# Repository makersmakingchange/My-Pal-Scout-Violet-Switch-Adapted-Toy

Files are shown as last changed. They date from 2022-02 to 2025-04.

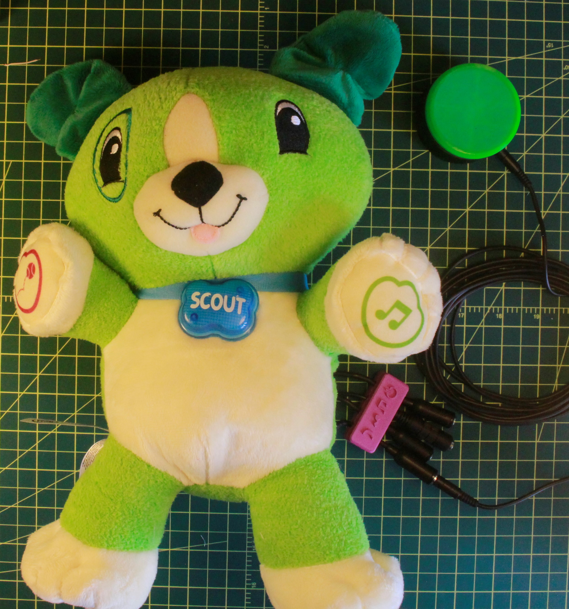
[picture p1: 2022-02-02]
Photos/_MG_9257 (2).JPG

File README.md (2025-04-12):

# My-Pal-Scout-Violet-Switch-Adapted-Toy
Solderless toy hack for My Pal toys that allows for switch adaptation

## Overview

The switch adapted My Pal Scout/Violet sings songs and can be controlled with accessible switches that have a 3.5mm jack. The My Pal is a LeapFrog toy that sings lullabies and learning songs, and has activities with numbers, animals, food, and more.

## Usage

You can use the My Pal Scout/Violet by plugging in one to four AT switches. The cable clamp labels which function each audio lead controls. Then, press the AT switches, or the in-toy buttons, to activate the various songs and activities.

## Build Instructions

You can build the My Pal Scout/Violet by following the Assembly Guide attached. Follow the “How to prep your 3.5mm headphone jack” tutorial first to prepare for this toy adaption.

## Bill of Materials
Links given in BOM under documentation

 - 1 x LeapFrog My Pal Scout or Violet Toy (https://www.amazon.ca/LeapFrog-Pal-Violet-English-Version/dp/B00D2KZ1ZY?th=1)
 - 4 x 3.5mm Female Headphone jacks (something like two of  these cut in half: (Amazon Canada)
 - 8 x Crimp Connectors (Amazon Canada)
 - 1 x 3D Printed Clamp
 - 2 x #4 Metal Screw, 3/8″ Length (Amazon Canada)
 - 1 x 4" Zip Tie (Amazon Canada)
 - 1 x 18" Zip Tie (Amazon Canada
 - Electrical Tape

Note: Other wire connections aside from the crimp connectors can be used, such as UR2 connectors, Marrettes, or even soldering the connections.

## Tools
 - Needle Nose Pliers (or Wire Crimpers, or Vise Grips)
 - Crimping tool is recommended if available
 - Wire Cutters
 - Wire Strippers

## Attribution

 - Original Device: ATMakers
 - Updated Design: Makers Making Change

<!-- ABOUT MMC START -->
## About Makers Making Change
[Makers Making Change Logo](https://www.makersmakingchange.com/)

Makers Making Change is a program of [Neil Squire](https://www.neilsquire.ca/), a Canadian non-profit that uses technology, knowledge, and passion to empower people with disabilities.

Makers Making Change leverages the capacity of community based Makers, Disability Professionals and Volunteers to develop and deliver affordable Open Source Assistive Technologies.

 - Website: [www.MakersMakingChange.com](https://www.makersmakingchange.com/)
 - GitHub: [makersmakingchange](https://github.com/makersmakingchange)
 - Bluesky: [@makersmakingchange.bsky.social](https://bsky.app/profile/makersmakingchange.bsky.social)
 - Instagram: [@makersmakingchange](https://www.instagram.com/makersmakingchange)
 - Facebook: [makersmakechange](https://www.facebook.com/makersmakechange)
 - LinkedIn: [Neil Squire Society](https://www.linkedin.com/company/neil-squire-society/)
 - Thingiverse: [makersmakingchange](https://www.thingiverse.com/makersmakingchange/about)
 - Printables: [MakersMakingChange](https://www.printables.com/@MakersMakingChange)

### Contact Us
For technical questions, to get involved, or to share your experience we encourage you to [visit our website](https://www.makersmakingchange.com/) or [contact us](https://www.makersmakingchange.com/s/contact).
<!-- ABOUT MMC END -->

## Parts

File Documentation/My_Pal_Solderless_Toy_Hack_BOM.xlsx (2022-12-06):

Device: My Pal Solderless Toy Hack |  |  |  |  |  | Total Cost | Total Print time (hr) | Total filament (g)
Version: V1.0 | Date Created: 1/31/2022 |  |  |  |  | $48.66 | 0.77 | 9.49
Commercial Parts:
Part type (Electrical. Mechanical, Sanitization, ect) | Part | Quantity Needed | Pkg Quantity | Price per package | Price per Unit | Price for qty needed |  | Link
Toy | My Pal Scout/Violet | 1 | 1 | $25.97 | $25.97 | $25.97 |  | https://www.amazon.ca/LeapFrog-Pal-Violet-English-Version/dp/B00D2KZ1ZY?th=1
Electrical | 3.5mm Female-Female Audio Leads | 2 | 1 | $9.99 | $9.99 | $19.98 |  | ANDTOBO Aux Connector ,3.5mm TRRS Female to Female Stereo Coupler Plug Adapter- 3.3 Ft : Amazon.ca: Electronics (https://www.amazon.ca/ANDTOBO-Connector-Female-Coupler-Adapter/dp/B08CXNHXZQ)
Electrical | Crimp Connectors | 8 | 100 | $16.29 | $0.16 | $1.30 |  | https://www.amazon.ca/dp/B09D6WSGBL?s=hi
Hardware | 4" Zip Tie | 1 | 300 | 10.59 | $0.04 | $0.04 |  | https://www.amazon.ca/Inch-300pcs-Nylon-Cable-White/dp/B07JHQFV29?s=hi
Hardware | 18" Zip Tie | 1 | 100 | 30.99 | $0.31 | $0.31 |  | https://www.amazon.ca/Industrial-Durable-Binding-Branches-Bundling/dp/B08B3S5Y65?s=hi
Hardware | #4 Metal Screw. 3/8" Length | 2 | 25 | 10.34 | $0.41 | $0.83 |  | https://www.amazon.ca/Prime-Line-9018921-Self-Tapping-Phillips-Stainless/dp/B074ZMZZC5?s=hi
3D Printed Parts ESTIMATED PRICING USING 1KG ROLL COST: | $25.00
Part | Description | Quantity Needed | TOTAL Mass (g) | Estimated Price | Print Time (Min) | Link
Cable Clamp Top and Bottom | Secures and labels the cables protruding from the toy. | 1 | 9.49 | $0.24 | 46
 |  |  |  | $0.00
 |  |  |  | $0.00
 |  |  |  | $0.00
 |  |  |  | $0.00
 |  |  | Total Print Cost: | $0.24
Tools for Assembly
#3 Philips Screwdriver
Flush Cutters
Pliers (Crimping tool reccomended)
Alternatives (if there are other sources for some parts link them below)
Part and description | Link
Marrettes in place of crimp connectors | https://www.amazon.ca/dp/B0009K6GB8/ref=twister_B06XWT633Y?th=1
UR2 connectors in place of crimp connectors | https://www.amazon.ca/YOLISTIC-Pack-Splice-Connector-Wire/dp/B098T7QF9L?s=hi
3.5mm Female-Female Audio Leads | 10-02148 Tensility International Corp | Cable Assemblies | DigiKey (https://www.digikey.ca/en/products/detail/tensility-international-corp/10-02148/7606595)

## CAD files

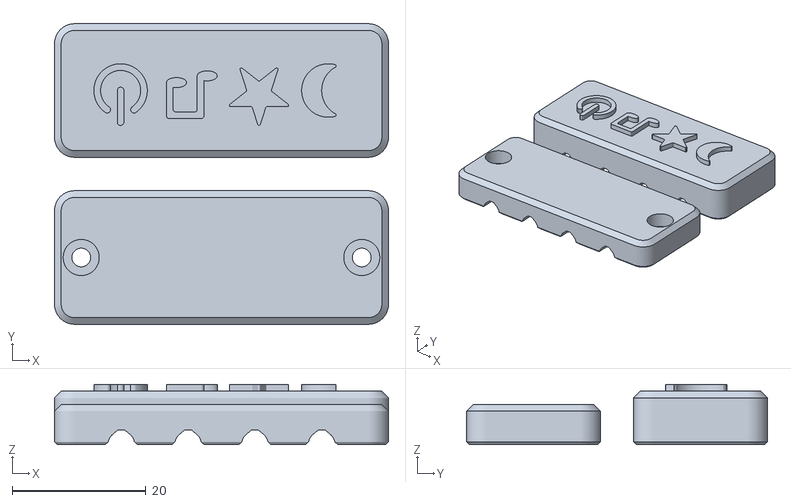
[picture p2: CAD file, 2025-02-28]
3D_Print_Files/Cable-Clamp.stl
50.0 x 45.0 x 9.00

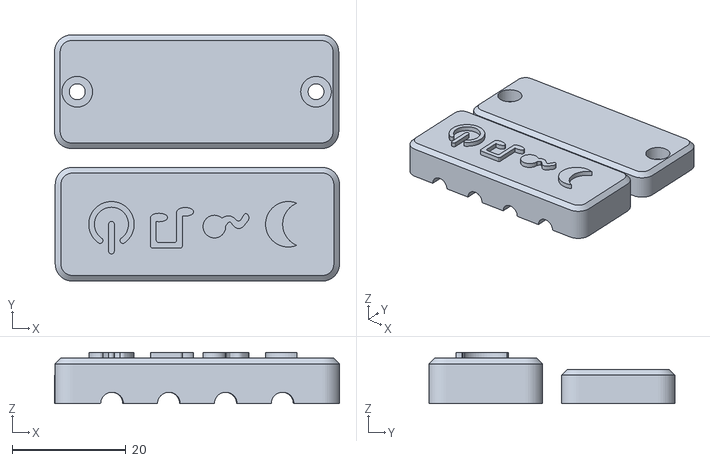
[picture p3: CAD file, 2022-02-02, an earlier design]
3D_Print_Files/Archive - Old version of toy/Cable-Clamp.stl
50.1 x 43.3 x 9.00

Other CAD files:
Design_Files/Cable-Clamp.step
Design_Files/Clamp v2 v11.f3d

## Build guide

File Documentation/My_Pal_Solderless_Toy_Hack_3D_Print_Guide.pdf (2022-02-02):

# 3D Printing Guide Device: My Pal Solderless Toy Hack

### Version: 1.0 Date: 2/1/2022

# Summary

Metrics | *Configuration 1*
Total Print Time (min) | 46
Total Number of Components | 2
Typical Total Mass (g) | 9.49
Typical Number of Print Setups | 1

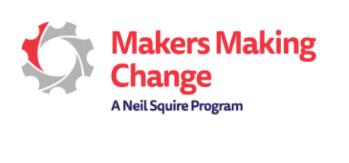
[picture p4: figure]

Print File Name | Qty | Total Print Time (min) | Mass (g) | Infill setting (%) | Material | Notes (support, orientation, special settings)
Cable Clamp.stl | 1 | 46 | 9.49 | 20 | PLA | -Can add a colour change at a layer height of 8.2mm to make the images stand out.

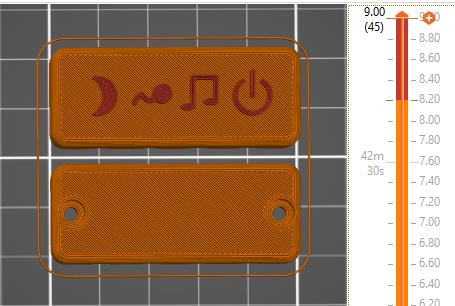
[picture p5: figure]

# Post-Processing

- You may need to clean up some filament from the top surface of the images. This can be done carefully with a knife by scraping off the loose filament.

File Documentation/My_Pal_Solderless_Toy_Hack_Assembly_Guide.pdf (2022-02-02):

# Toy Hack

## COMPONENTS AND TOOLS

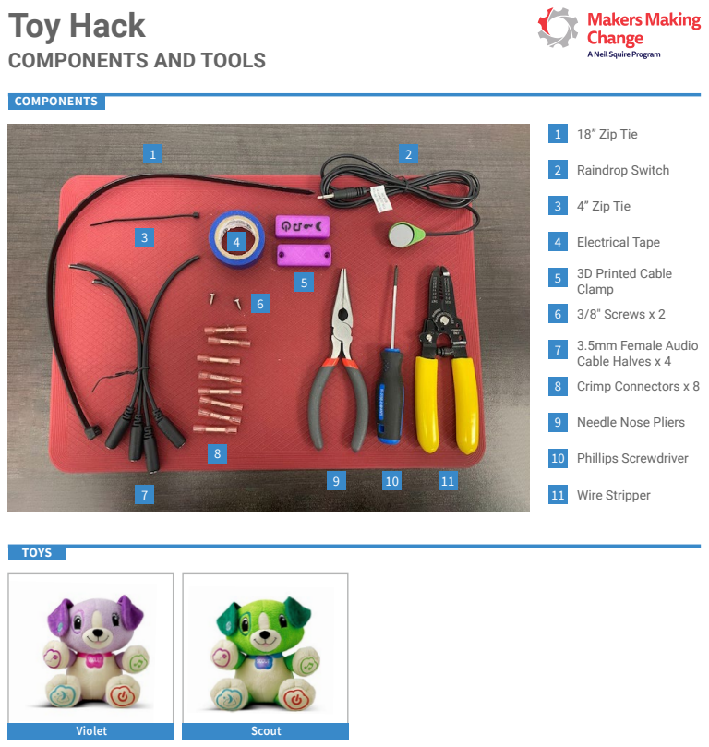
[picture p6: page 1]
COMPONENTS; TOYS; Violet; Scout; 18” Zip Tie; Raindrop Switch; 4” Zip Tie; Electrical Tape; 3D Printed Cable; Clamp; 3/8″ Screws x 2; Crimp Connectors x 8; Needle Nose Pliers; Phillips Screwdriver; Wire Stripper; 3.5mm Female Audio; Cable Halves x 4

V1.0 | November 2021

## My Pal Solderless Toy Hack

## ASSEMBLY GUIDE

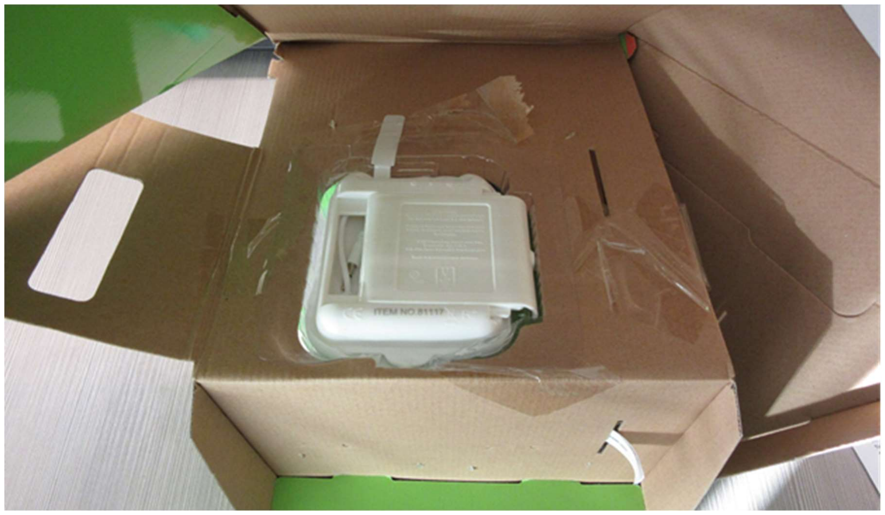
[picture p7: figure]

© 2021 by <Author>. This work is licensed under the CC BY SA 4.0 License: http://creativecommons.org/licenses/by-sa/4.0
Files available at <Replace with MMC Library Link> | Page 2 of 9

Assembly Instructions

### Step 1

Opening the toy:

a) Open the package carefully to unveil the internal battery case.

### Note: It is ideal to leave the toy in the box when doing this hack so it can easily be

repackaged and sent to the end user.

V1.0 | November 2021

## My Pal Solderless Toy Hack

## ASSEMBLY GUIDE

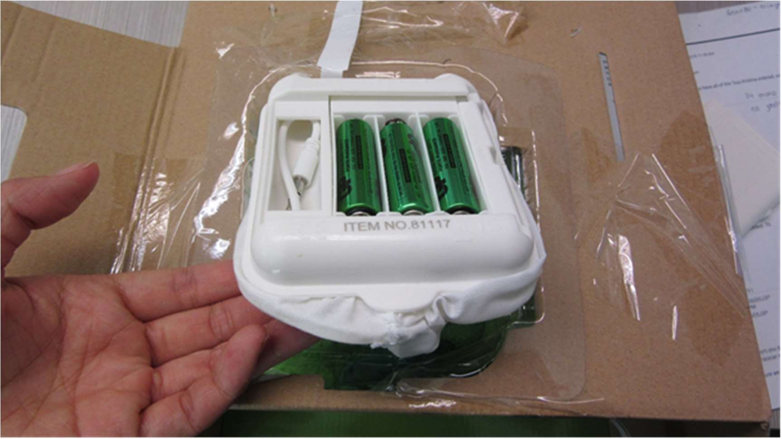
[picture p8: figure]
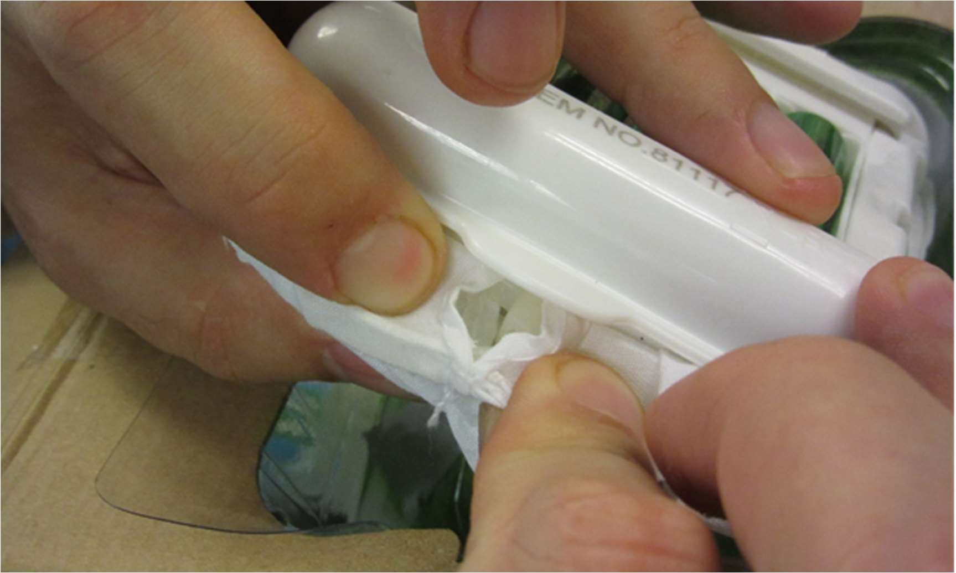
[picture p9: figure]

Files available at <Replace with MMC Library Link> | Page 3 of 9
b) Remove the case from the package but don’t cut the zip tie attaching Violet/Scout to the box. Take out the three AA batteries and set them aside.
c) Near the bottom of the case by the printed “Item No.”, carefully tear the fabric by 1cm to expose the zip tie underneath. Cut off the zip tie knot to release the casing from the fabric.
d) Carefully pull the white casing out of the fabric to expose the wires coming out the back.

V1.0 | November 2021

## My Pal Solderless Toy Hack

## ASSEMBLY GUIDE

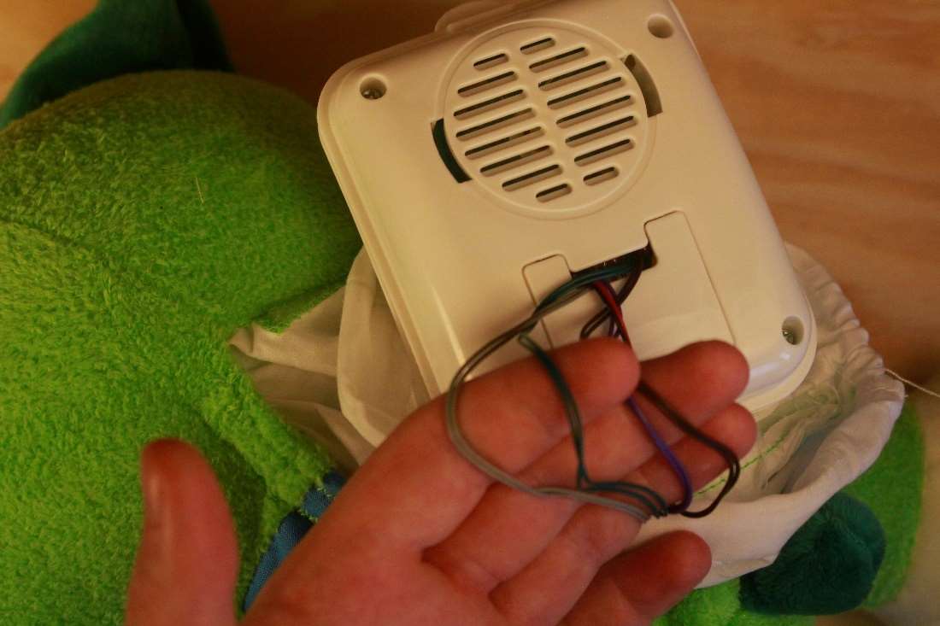
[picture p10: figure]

Files available at <Replace with MMC Library Link> | Page 4 of 9

### Step 2

Wire connections:

a) Locate the pairs of wires going down each limb of the toy and select one pair. The 4 wire pairs in this toy are coloured as grey, green, purple, and brown. (Order as seen in the photo below)
b) Cut one of the wires in the pair and strip 1cm from each new end, then twist these exposed ends back together. Do the same with the other wire in the pair.

## My Pal Solderless Toy Hack

## ASSEMBLY GUIDE

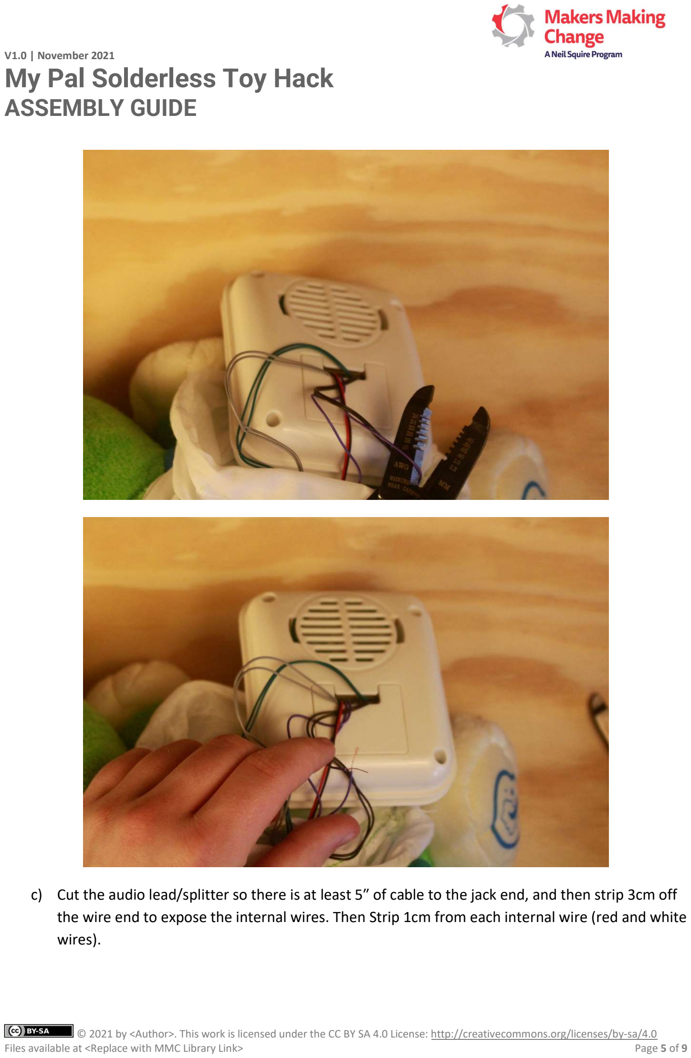
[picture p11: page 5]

V1.0 | November 2021
Files available at <Replace with MMC Library Link> | Page 5 of 9
c) Cut the audio lead/splitter so there is at least 5″ of cable to the jack end, and then strip 3cm off the wire end to expose the internal wires. Then Strip 1cm from each internal wire (red and white wires).

V1.0 | November 2021

## My Pal Solderless Toy Hack

## ASSEMBLY GUIDE

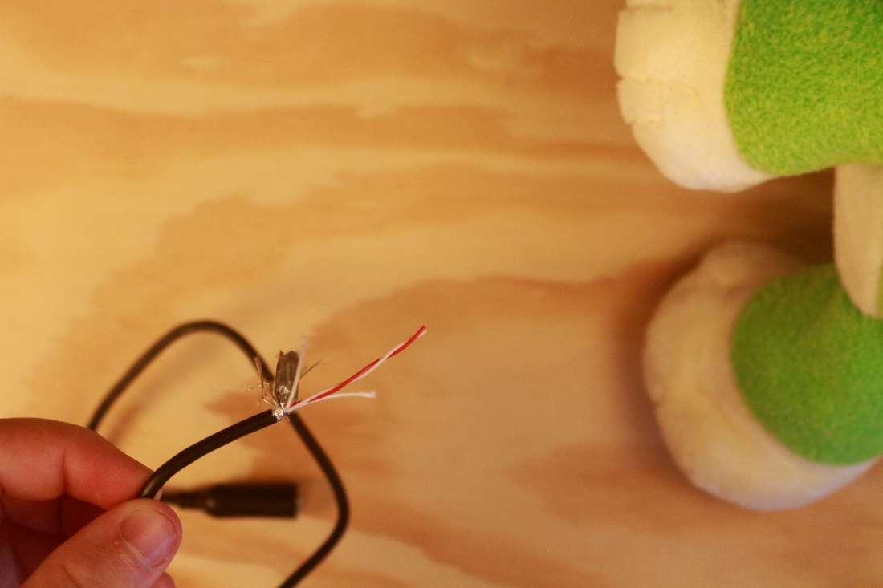
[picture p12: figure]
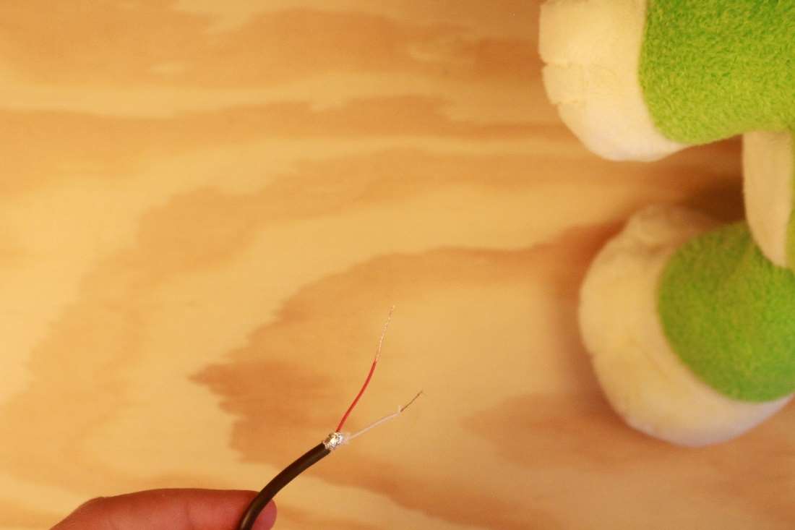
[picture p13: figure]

Files available at <Replace with MMC Library Link> | Page 6 of 9
d) Using a crimp connector, insert the twisted together wires from the toy in one side and one of the newly exposed audio lead wires in the other, then crimp the connector with the pliers. Repeat with the other wire from the pair.
Note: This step may be easier if these specified wires are all twisted together and inserted into one end of the crimp connector. Marrettes or other such cable connectors may be used instead.

## My Pal Solderless Toy Hack

## ASSEMBLY GUIDE

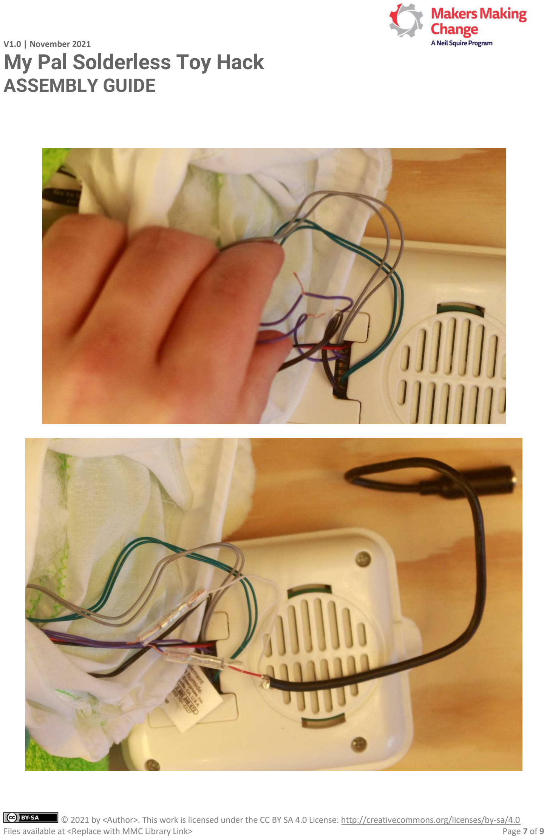
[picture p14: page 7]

V1.0 | November 2021
Files available at <Replace with MMC Library Link> | Page 7 of 9

V1.0 | November 2021

## My Pal Solderless Toy Hack

## ASSEMBLY GUIDE

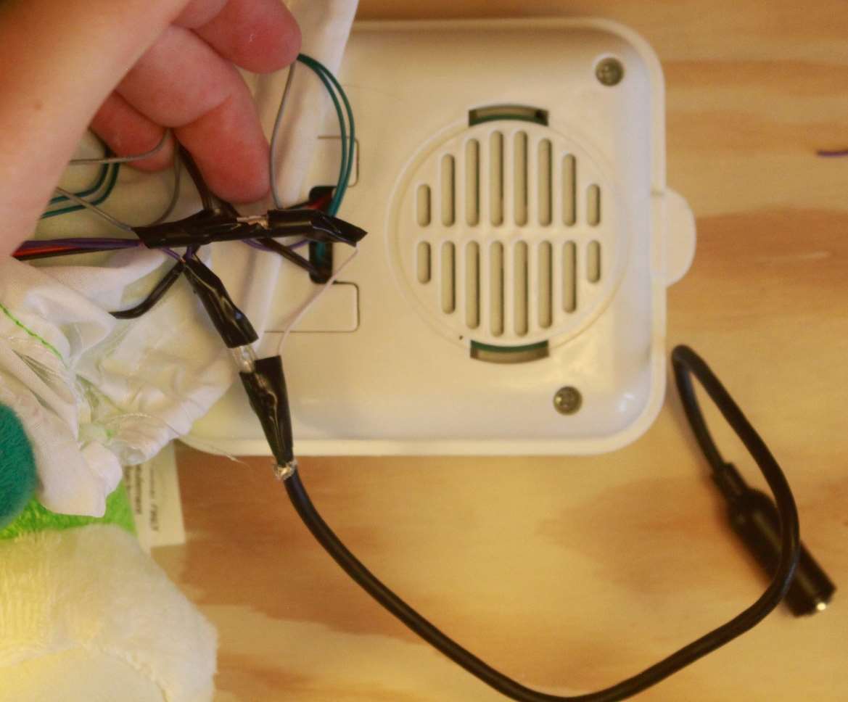
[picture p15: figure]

Files available at <Replace with MMC Library Link> | Page 8 of 9
e) Wrap the connection with electrical tape and repeat these steps for each pair of wires.
f) Insert the batteries back into the toy and test each jack with a switch. Ensure the buttons in the paws of the toy also still work.

### Step 3

Closing the toy:

a) Pull the female audio leads through to the outside and using the new zip tie, “reseal” the casing back into the fabric of the plushy. Then, cut off the excess end of the zip tie and tuck the head of the zip tie into the fabric.

V1.0 | November 2021

## My Pal Solderless Toy Hack

## ASSEMBLY GUIDE

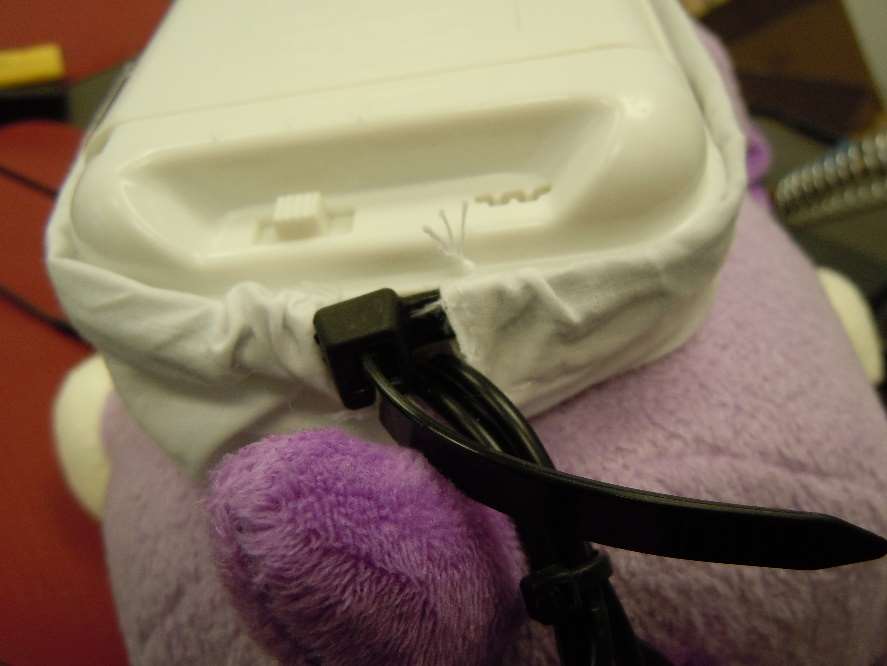
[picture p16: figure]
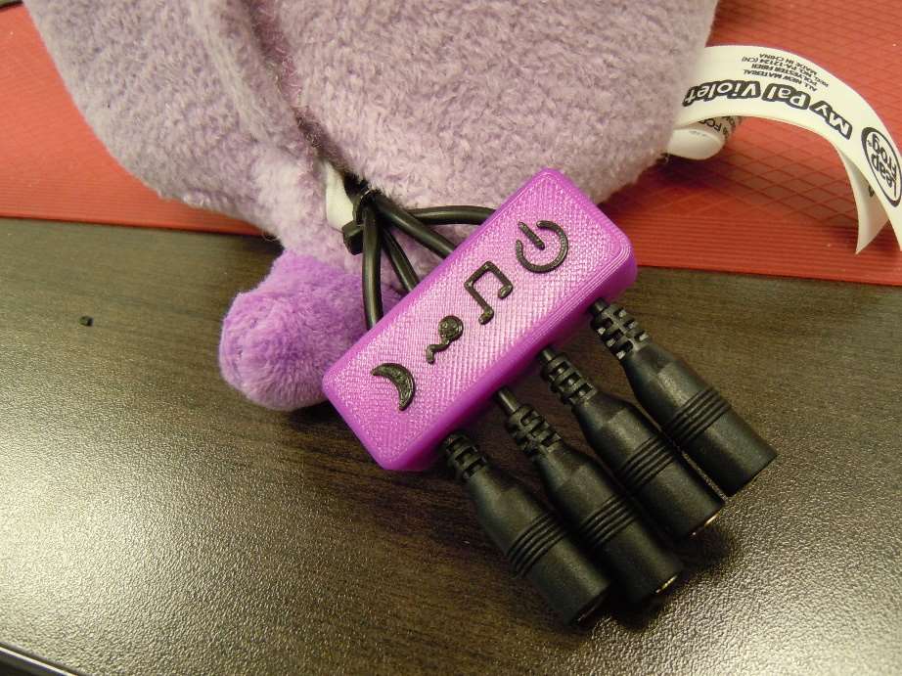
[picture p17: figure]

Files available at <Replace with MMC Library Link> | Page 9 of 9
b) Secure the audio cables in the cable clamp, ensuring the jacks go in their corresponding spots based on the images that match the images on the toy’s paws. This can be done using a switch to test each jack and pushing on the buttons in the paws to compare.
c) Secure all four cables between the toy and the cable clamp together with the small zip tie.
d) Reseal the box as it was before. Note that the above toy is removed from it’s box and if you completed the toy in the box, it will look more like the image in step 1 but with the cables and cable clamp protruding from the bottom.

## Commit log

2025-02-28 Cable clamp update
    Updated cable clamp to match symbols on new toy, and to improve printability. Added design files as well.
    [Cable-Clamp.step, Cable-Clamp.stl, Clamp v2 v11.f3d]
2025-02-28 Update Cable-Clamp.stl
    Re-oriented STL
    [Cable-Clamp.stl]
